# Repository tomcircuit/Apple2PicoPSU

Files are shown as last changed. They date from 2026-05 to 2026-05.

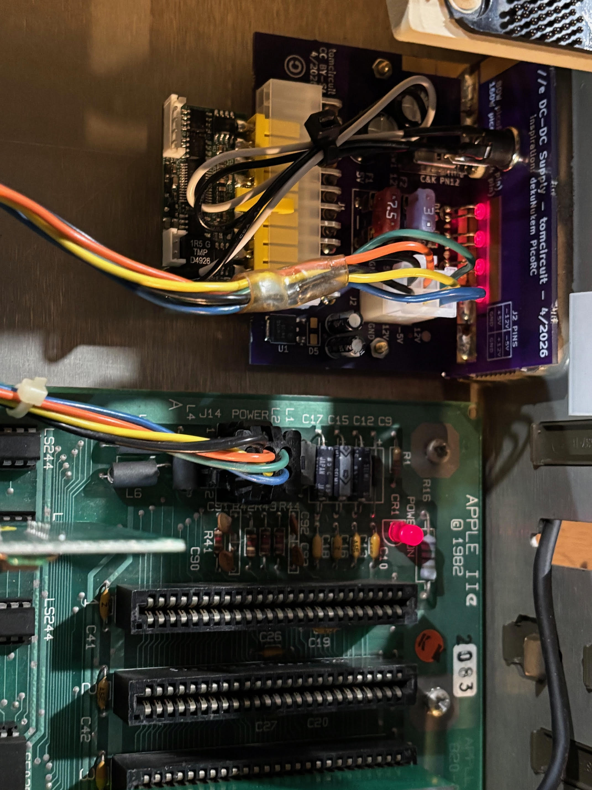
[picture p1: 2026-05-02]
Media/installed_interior.jpg

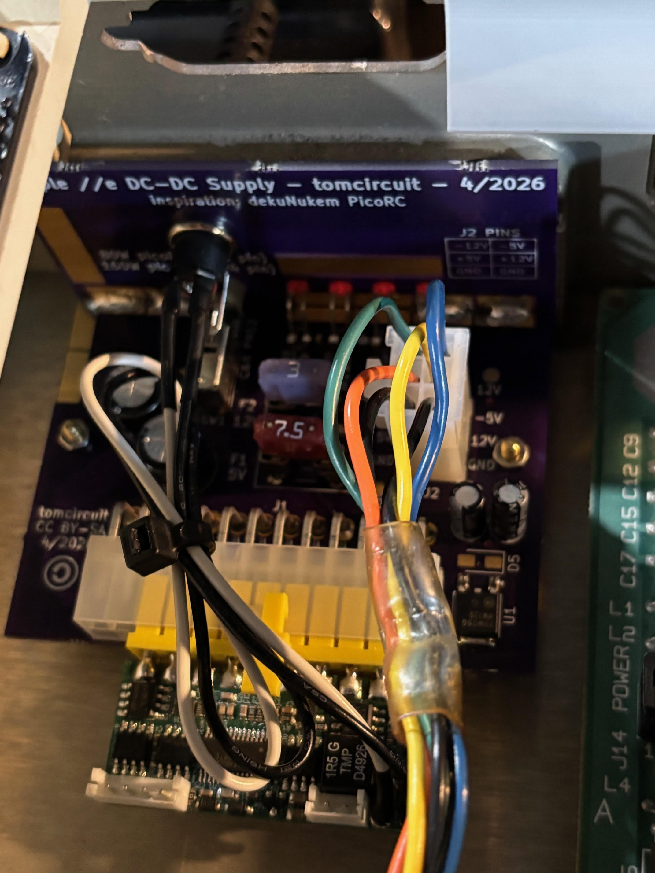
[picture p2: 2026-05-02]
Media/installed_interior_2.jpg

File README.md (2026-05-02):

# Apple 2 Pico PSU
12V Input Power Supply retrofit for vintage Apple //e  computers

Many vintage Apple(R) ][ and // series computers suffer from power supply failure. These computers were fitted with switching power supplies (SMPS) that, for the time, were notable for their lightweight, quiet, and efficient characteristics. Time, however, has not been kind to these supplies, which are vulnerable to aging. There is no drop-in replacment unit, so most enthusiasts are forced to either repair their supply or replace with a modern retrofit. This project is of the latter type, and my motivation was when my Apple //e computer's power supply emitted the dreaded "magic smoke" (AFTER a complete re-cap, mind you) and resisted my efforts at repair.

First and foremost, this project is insprired by the "PicoRC" project family by DekuNukem, currently found here: https://github.com/dekuNukem/PicoRC
Note that that project is licensed under MIT License terms:

```
MIT License

Copyright (c) 2022 dekuNukem

Permission is hereby granted, free of charge, to any person obtaining a copy
of this software and associated documentation files (the "Software"), to deal
in the Software without restriction, including without limitation the rights
to use, copy, modify, merge, publish, distribute, sublicense, and/or sell
copies of the Software, and to permit persons to whom the Software is
furnished to do so, subject to the following conditions:

The above copyright notice and this permission notice shall be included in all
copies or substantial portions of the Software.

THE SOFTWARE IS PROVIDED "AS IS", WITHOUT WARRANTY OF ANY KIND, EXPRESS OR
IMPLIED, INCLUDING BUT NOT LIMITED TO THE WARRANTIES OF MERCHANTABILITY,
FITNESS FOR A PARTICULAR PURPOSE AND NONINFRINGEMENT. IN NO EVENT SHALL THE
AUTHORS OR COPYRIGHT HOLDERS BE LIABLE FOR ANY CLAIM, DAMAGES OR OTHER
LIABILITY, WHETHER IN AN ACTION OF CONTRACT, TORT OR OTHERWISE, ARISING FROM,
OUT OF OR IN CONNECTION WITH THE SOFTWARE OR THE USE OR OTHER DEALINGS IN THE
SOFTWARE.
```

I did not directly modify the Eagle PCB nor Schematic files, and this work is my own, but I do feel that it is only proper to give DekuNukem attribution for the inspiration for this project. I license my project under CC-BY-SA-4.0 which can accept an MIT License as an "inbound license", in the event that my work is determined to be derivative after all.

There, that out of the way...

It's a **Great Idea** to move the AC-DC converter to the **outside of the Apple's case** for many reasons some of which are: it's heavy, it generates heat, and it allows for the possiblity to scale the PSU Wattage as required by the peripheral load. Any 12VDC supply with sufficient wattage and mating connector can be used, so that only 12VDC goes into the computer via the rear panel.

The **PicoPSU** units that are aimed at Small Form Factor (SFF) PC's are an ideal solution to convert the incoming 12VDC to +5V, +15V and -12V. These are available from many sources, in varying Wattages. I chose an 80W type for my own use, which should be more than sufficient. All that is missing is the -5V which is (questionably) required by the Apple motherboard.

Like the PicoRC for the Apple, my Apple2PicoPSU provides a power switch, a 24-pin Molex connector for the PicoPSU, fuses for the +5V and +12V voltage rails, and a -5V regulator for the 'missing' rail. I adoped a similar "PCB-welded" construction of a back panel and circuit board, because it seemed like a very convenient way to satisfy the mechanical aspects.

Improvements over the original PicoRC for the Apple are the following:
* power switch suitable for switching the low-current PicoPSU enable
* the 7905 voltage regulator would benefit from some sort of heatsinking
* LED for each voltage rail, visible from the outside of the case
* copper tracks sized sufficiently for the anticipated current demand

It is this last point in particular that really drove me to re-engineer this concept; I am quite skeptical of the copper track widths used in the original. I have sized the copper tracks for at least 8A on the 5V rail, and 4A on the 12V rail, assuming 1oz Cu and a modest 15C temperature rise over ambient.

My project was executed in the very capable open-source and "completely free" KiCad 10.0 which is well supported by the usual Operating Systems suspects...

Complete project writeup, including assembly instructions, can be found on Hackaday
https://hackaday.io/project/205643-a-modern-psu-for-my-apple-e

tomcircuit
01-MAY-2026

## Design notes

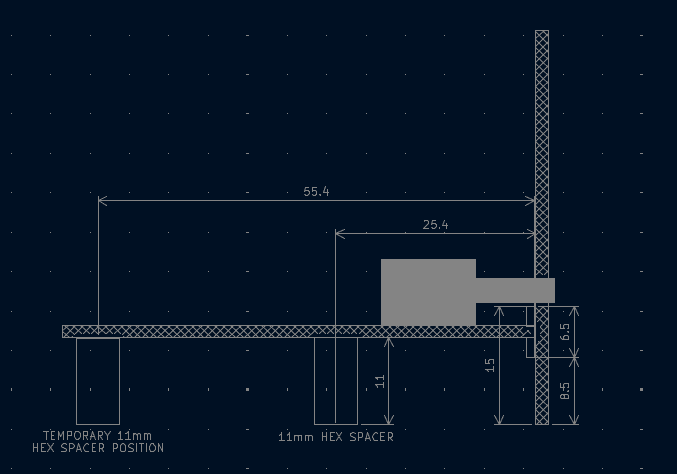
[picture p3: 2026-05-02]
Media/mechanical_assy_side.png

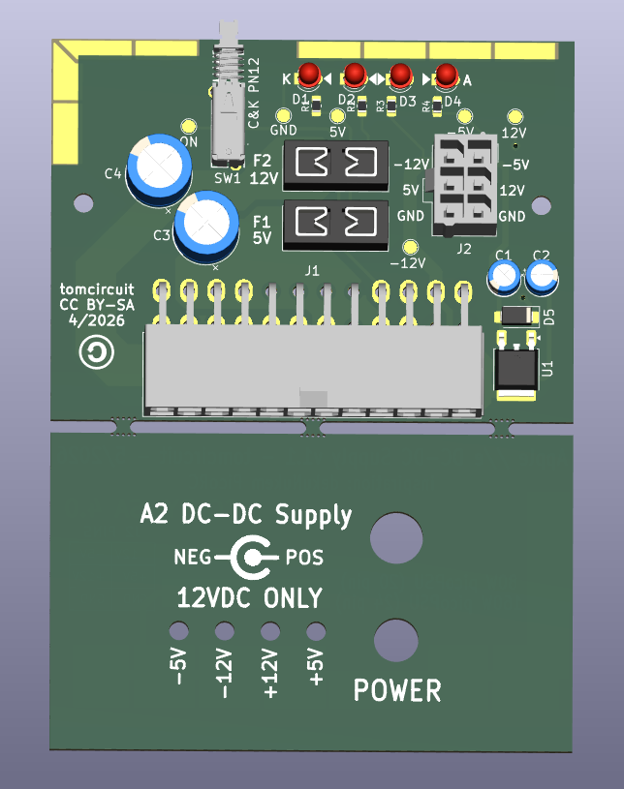
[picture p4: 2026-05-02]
Media/kicad_3d_model.png

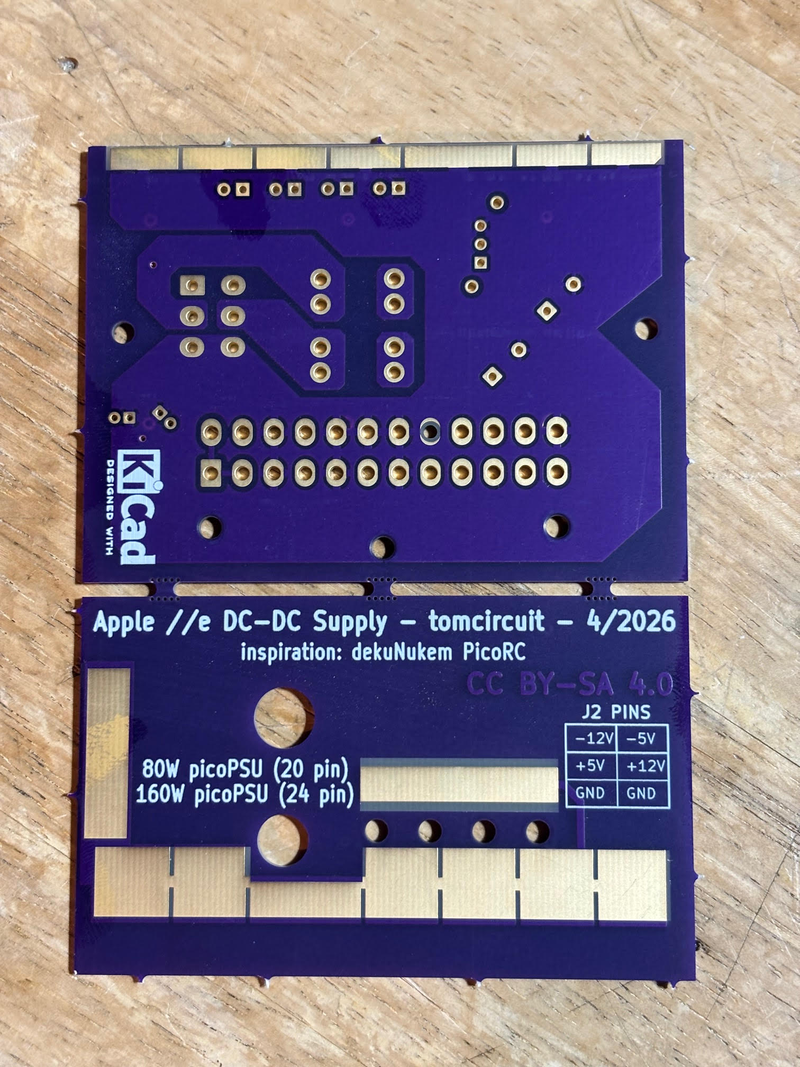
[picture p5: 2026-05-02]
Media/pcb_bare_bottom.jpg

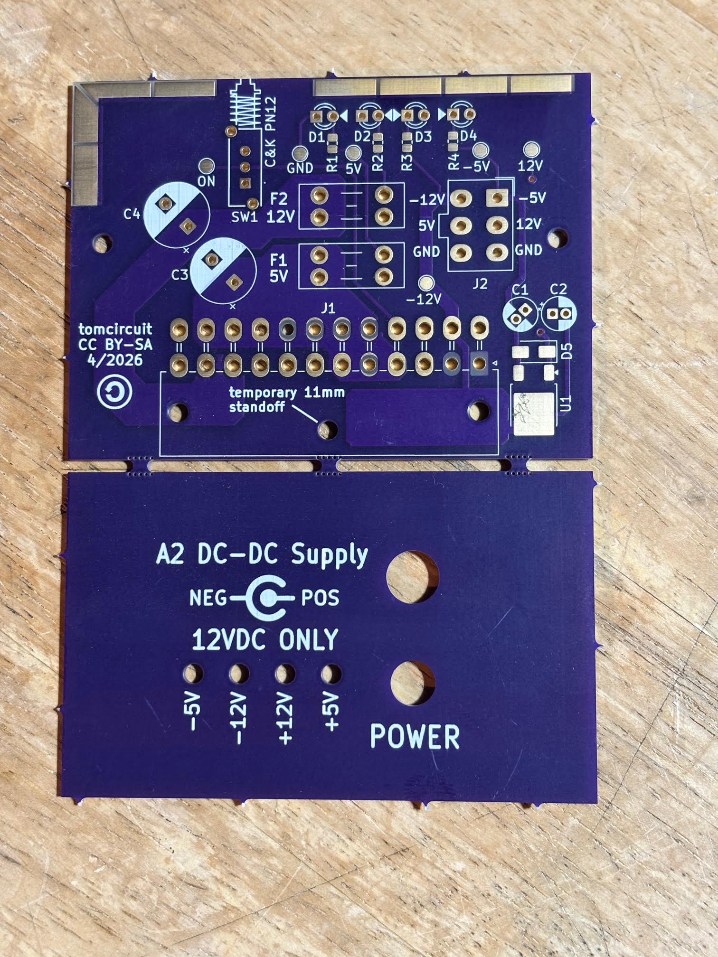
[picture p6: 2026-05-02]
Media/pcb_bare_top.jpg

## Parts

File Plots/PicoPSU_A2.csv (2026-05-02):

Id | Designator | Footprint | Quantity | Designation | Supplier and ref
1 | C1 | CP_Radial_D5.0mm_P2.00mm | 1 | 1uF
2 | C2 | CP_Radial_D5.0mm_P2.00mm | 1 | 2.2uF
3 | C3, C4 | CP_Radial_D10.0mm_P5.00mm | 2 | 470uF
4 | D1 | LED_D3.0mm | 1 | 5V
5 | D2 | LED_D3.0mm | 1 | 12V
6 | D3 | LED_D3.0mm | 1 | -12V
7 | D4 | LED_D3.0mm | 1 | -5V
8 | D5 | D_SMA | 1 | US1A
9 | F1 | Fuseholder_Blade_Mini_Keystone_3568 | 1 | 5V
10 | F2 | Fuseholder_Blade_Mini_Keystone_3568 | 1 | 12V
11 | J1 | Molex_Mini-Fit_Jr_5569-24A2_2x12_P4.20mm_Horizontal | 1 | PICO PSU
12 | J2 | Molex_Mini-Fit_Jr_5566-06A_2x03_P4.20mm_Vertical | 1 | APPLE MB
13 | R1, R4 | R_0805_2012Metric_Pad1.20x1.40mm_HandSolder | 2 | 330
14 | R2, R3 | R_0805_2012Metric_Pad1.20x1.40mm_HandSolder | 2 | 1K
15 | SW1 | PN12SHSA03QE | 1 | POWER
16 | TP5 | TestPoint_Pad_D2.0mm | 1 | ON
17 | U1 | TO-252-2 | 1 | MC79M05

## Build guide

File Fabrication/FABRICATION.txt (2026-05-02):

Here are Gerber and NC Drill files that are necessary for PCB fabrication

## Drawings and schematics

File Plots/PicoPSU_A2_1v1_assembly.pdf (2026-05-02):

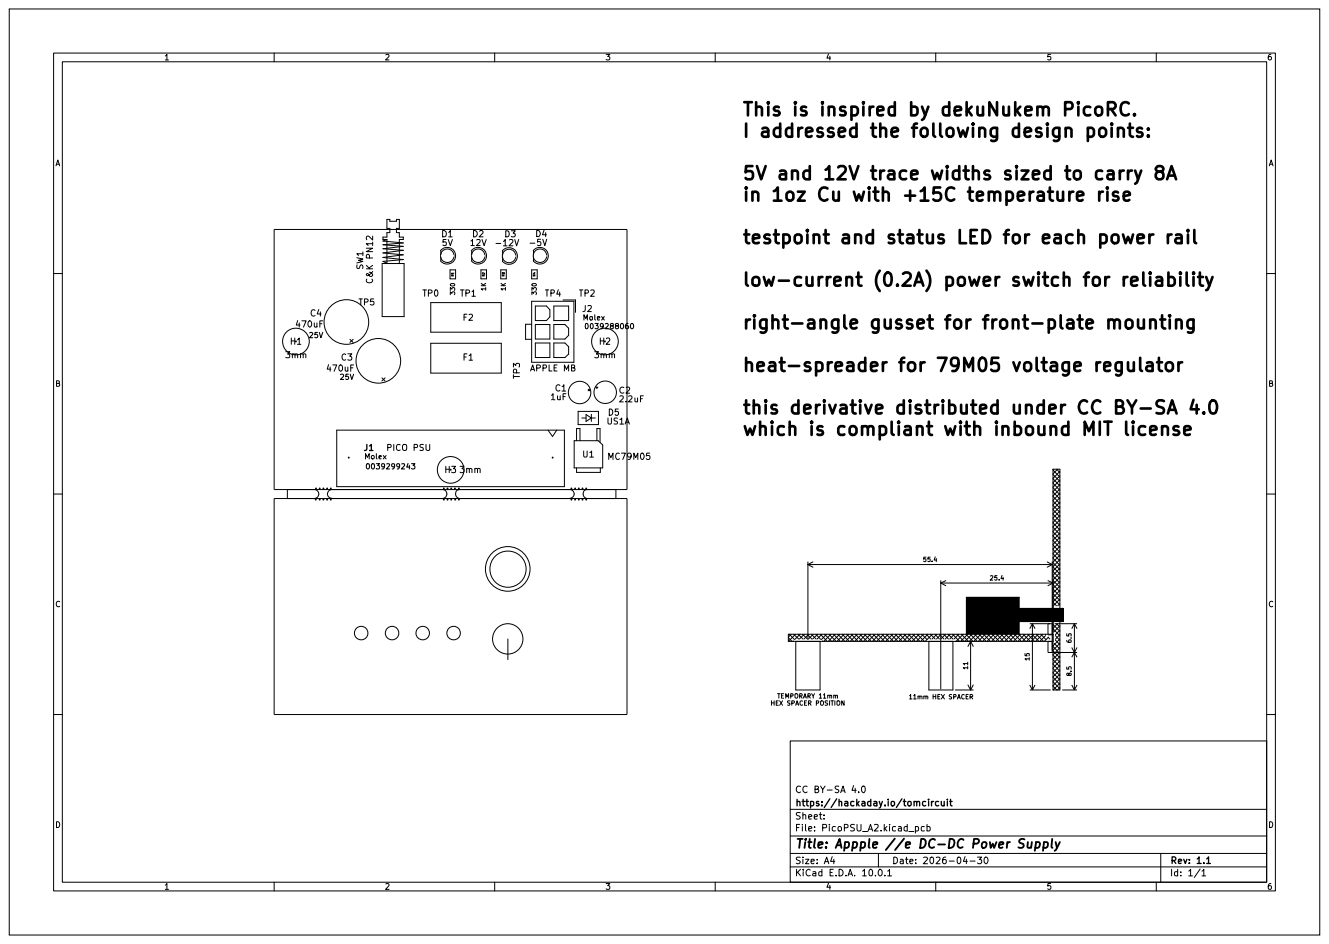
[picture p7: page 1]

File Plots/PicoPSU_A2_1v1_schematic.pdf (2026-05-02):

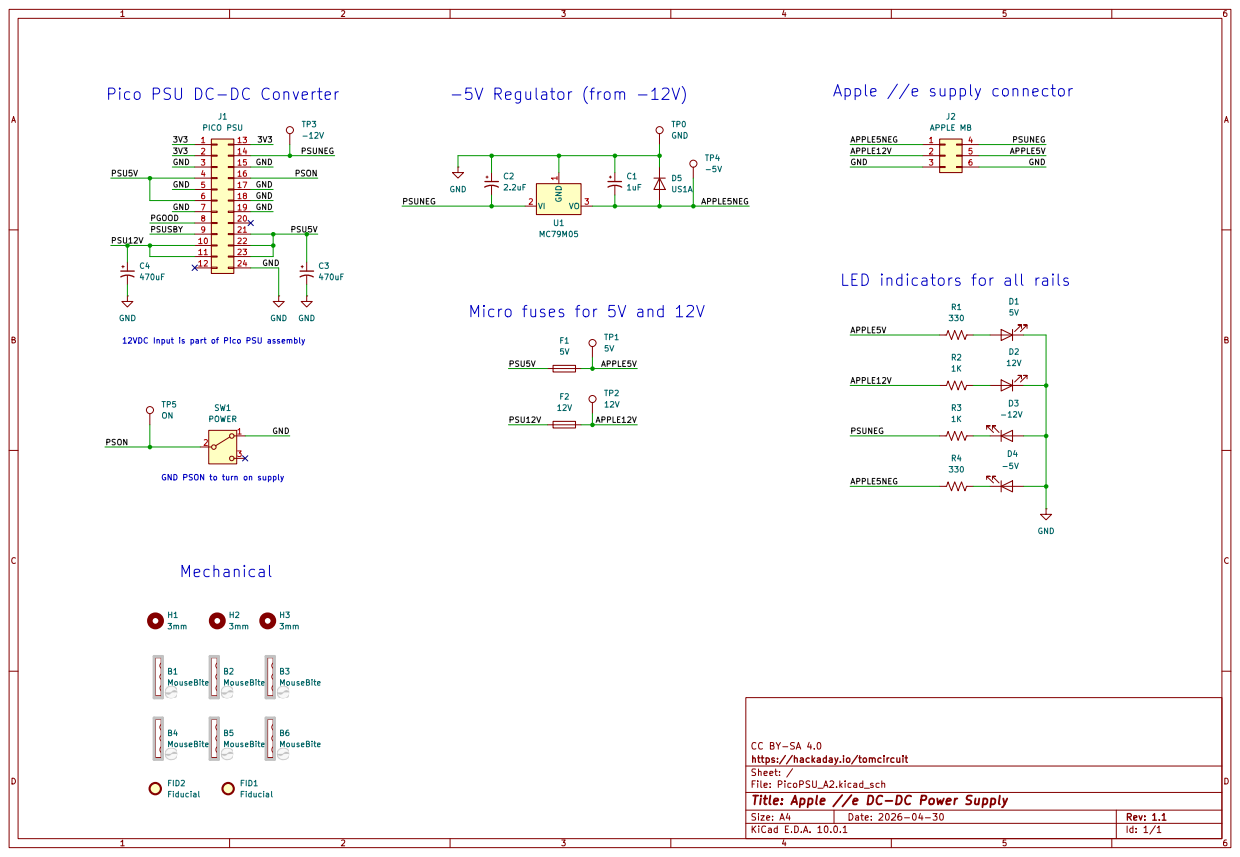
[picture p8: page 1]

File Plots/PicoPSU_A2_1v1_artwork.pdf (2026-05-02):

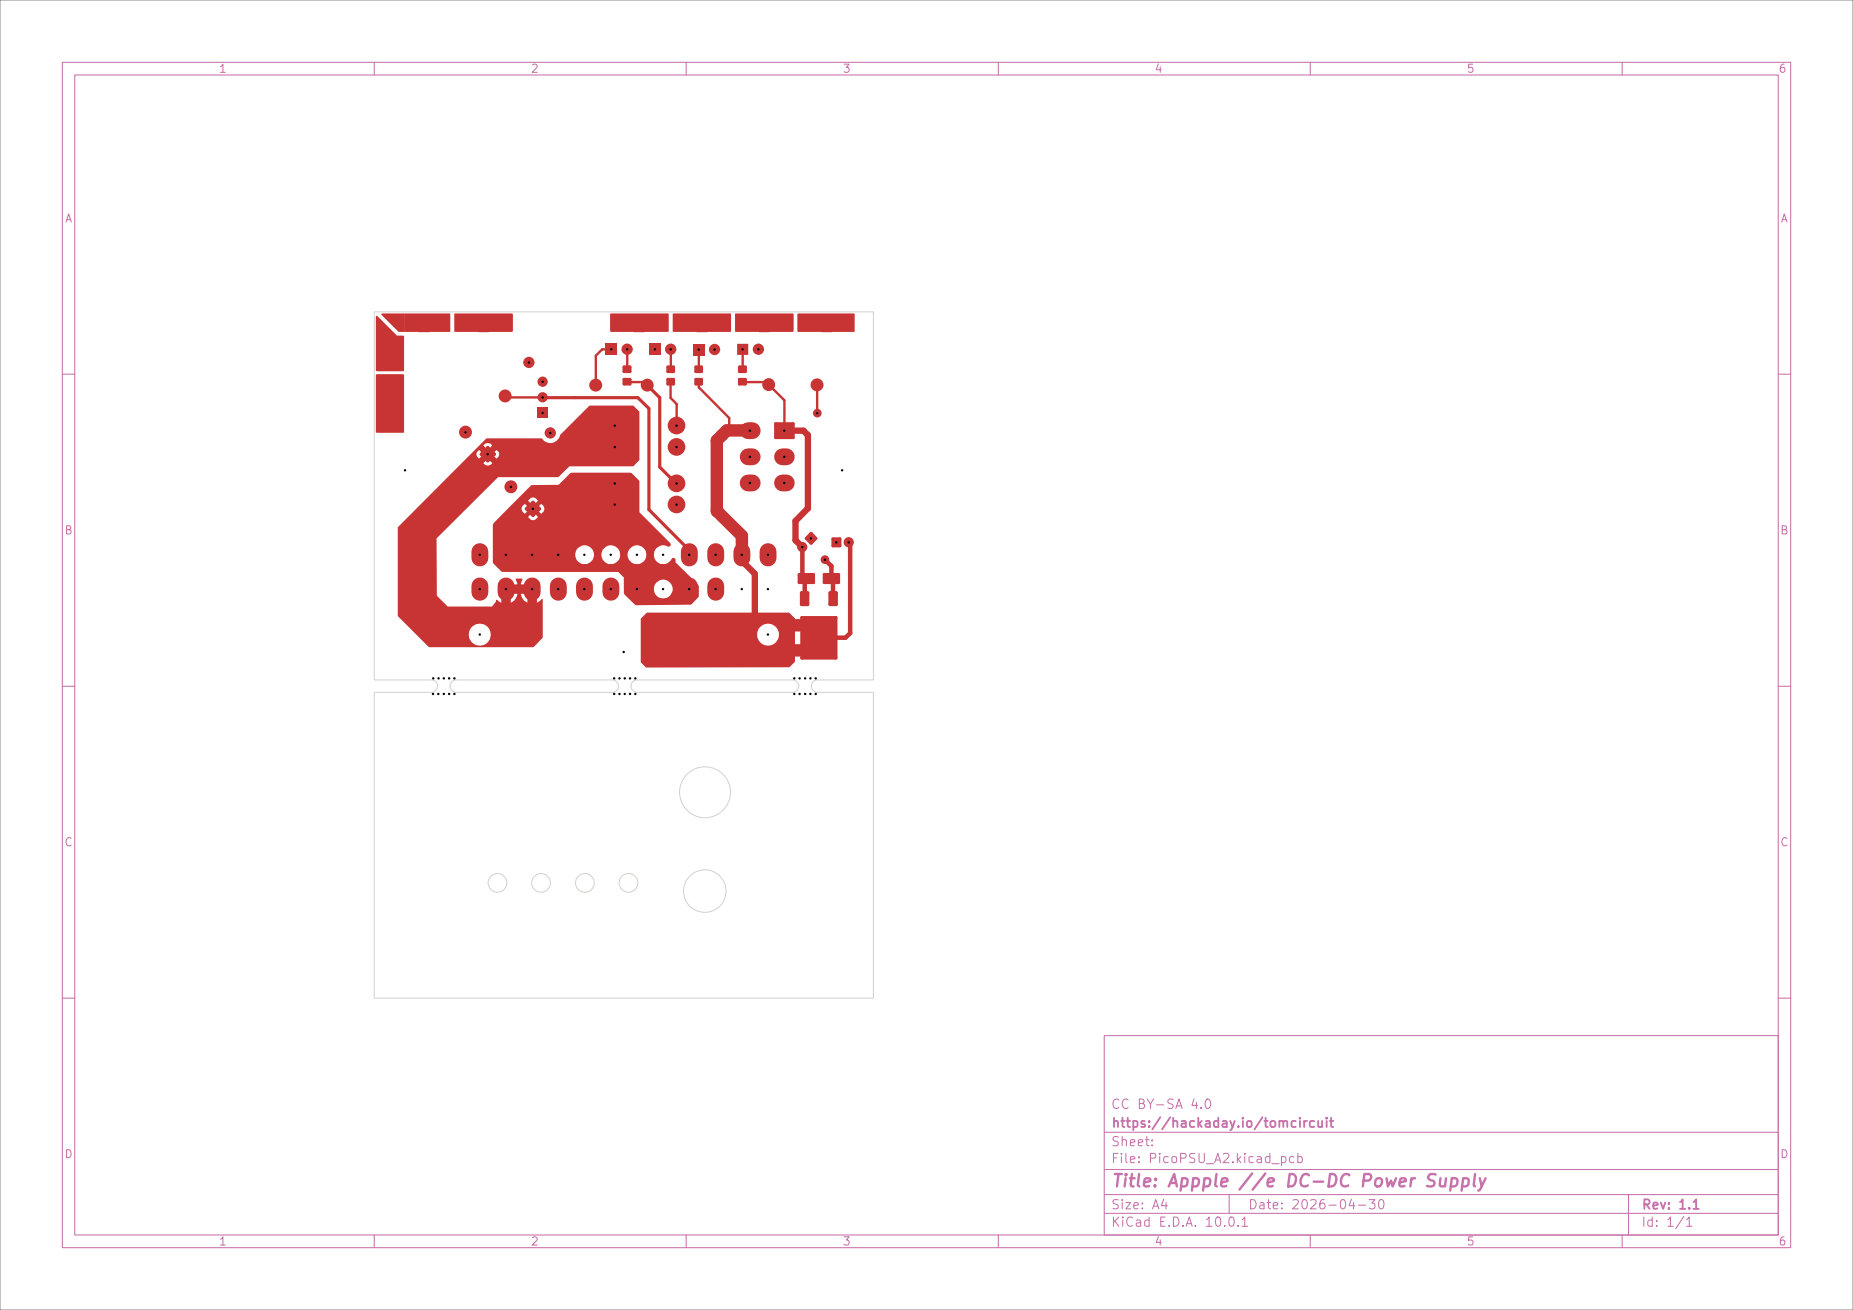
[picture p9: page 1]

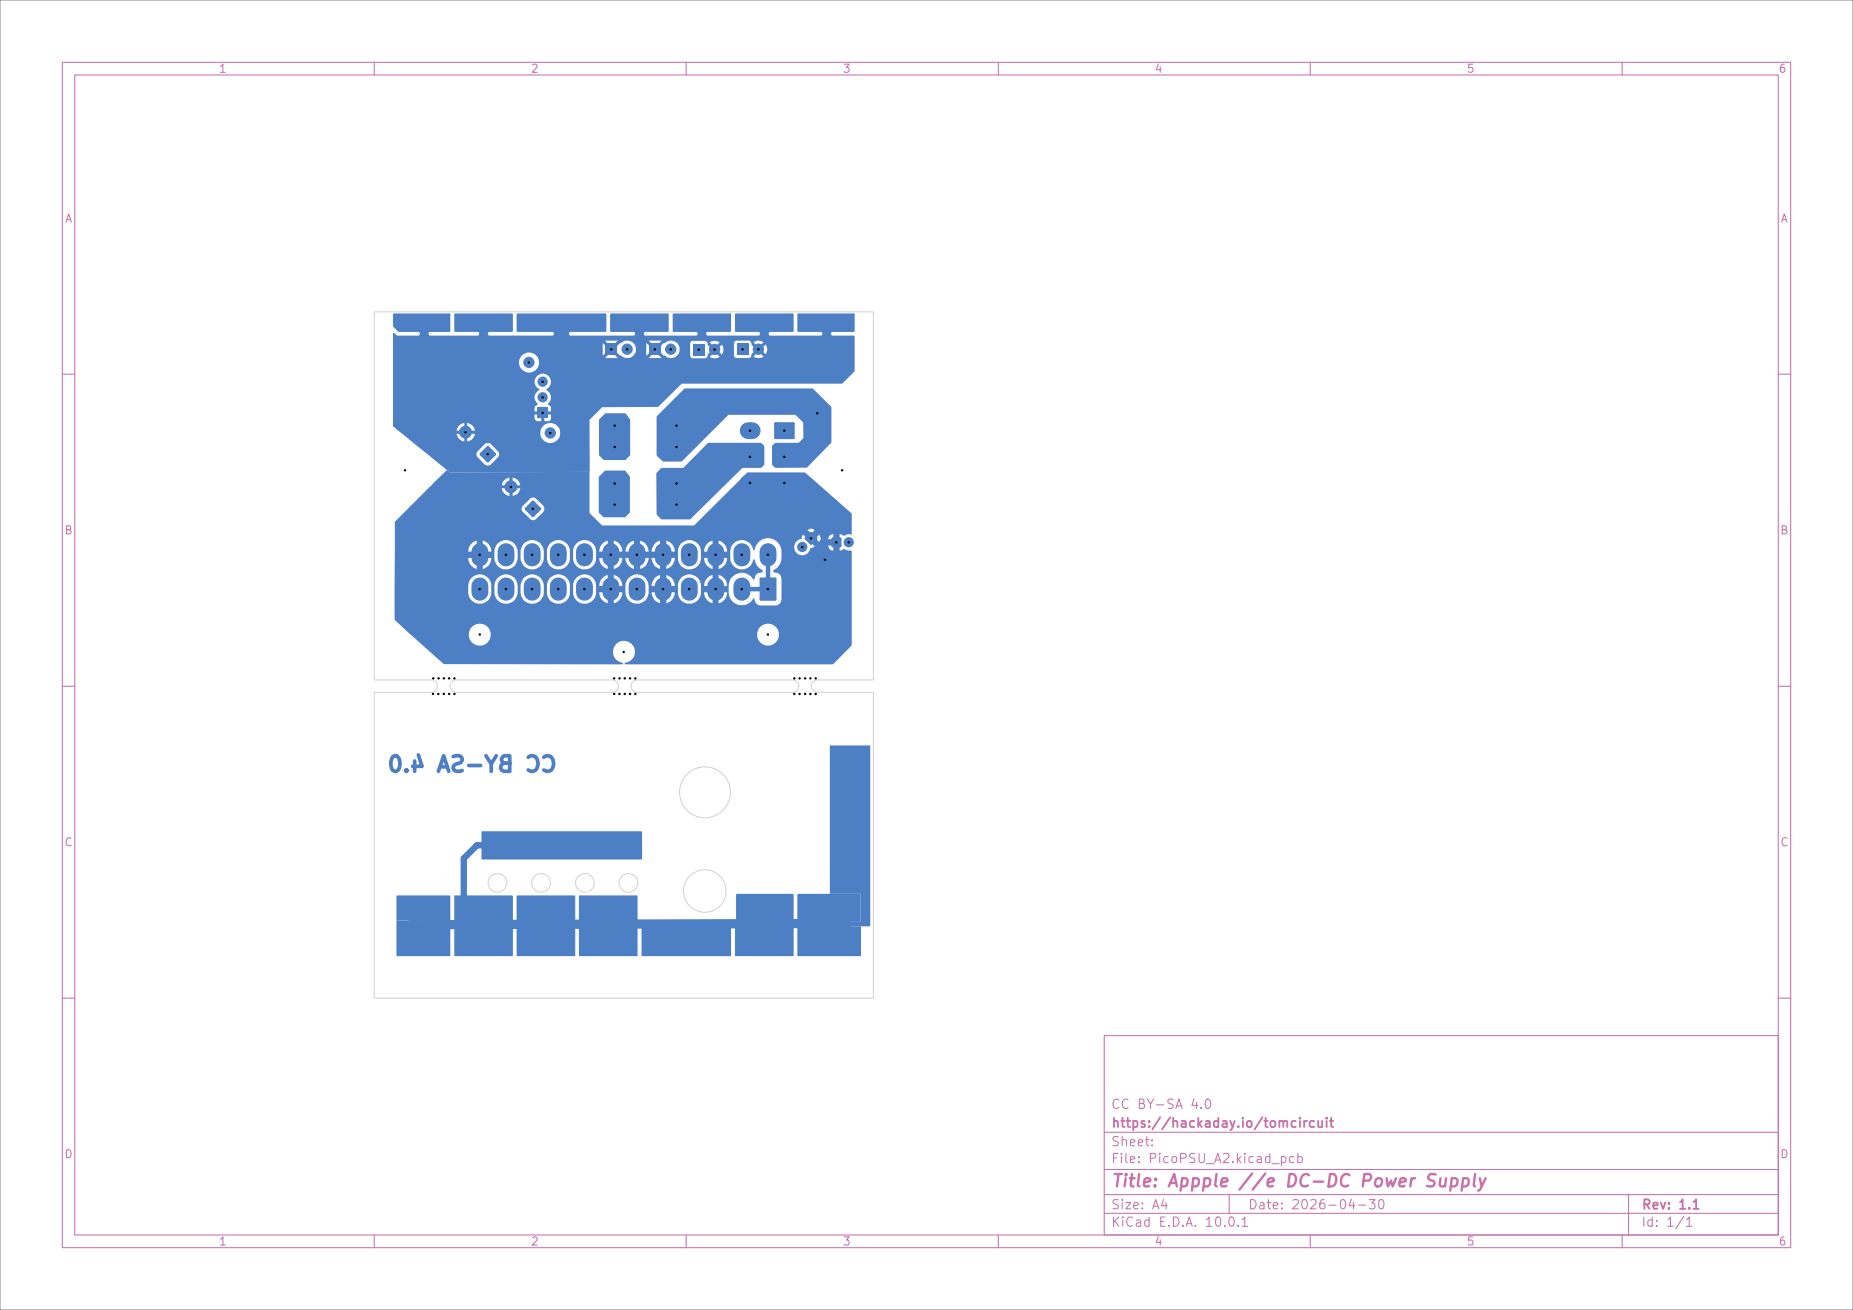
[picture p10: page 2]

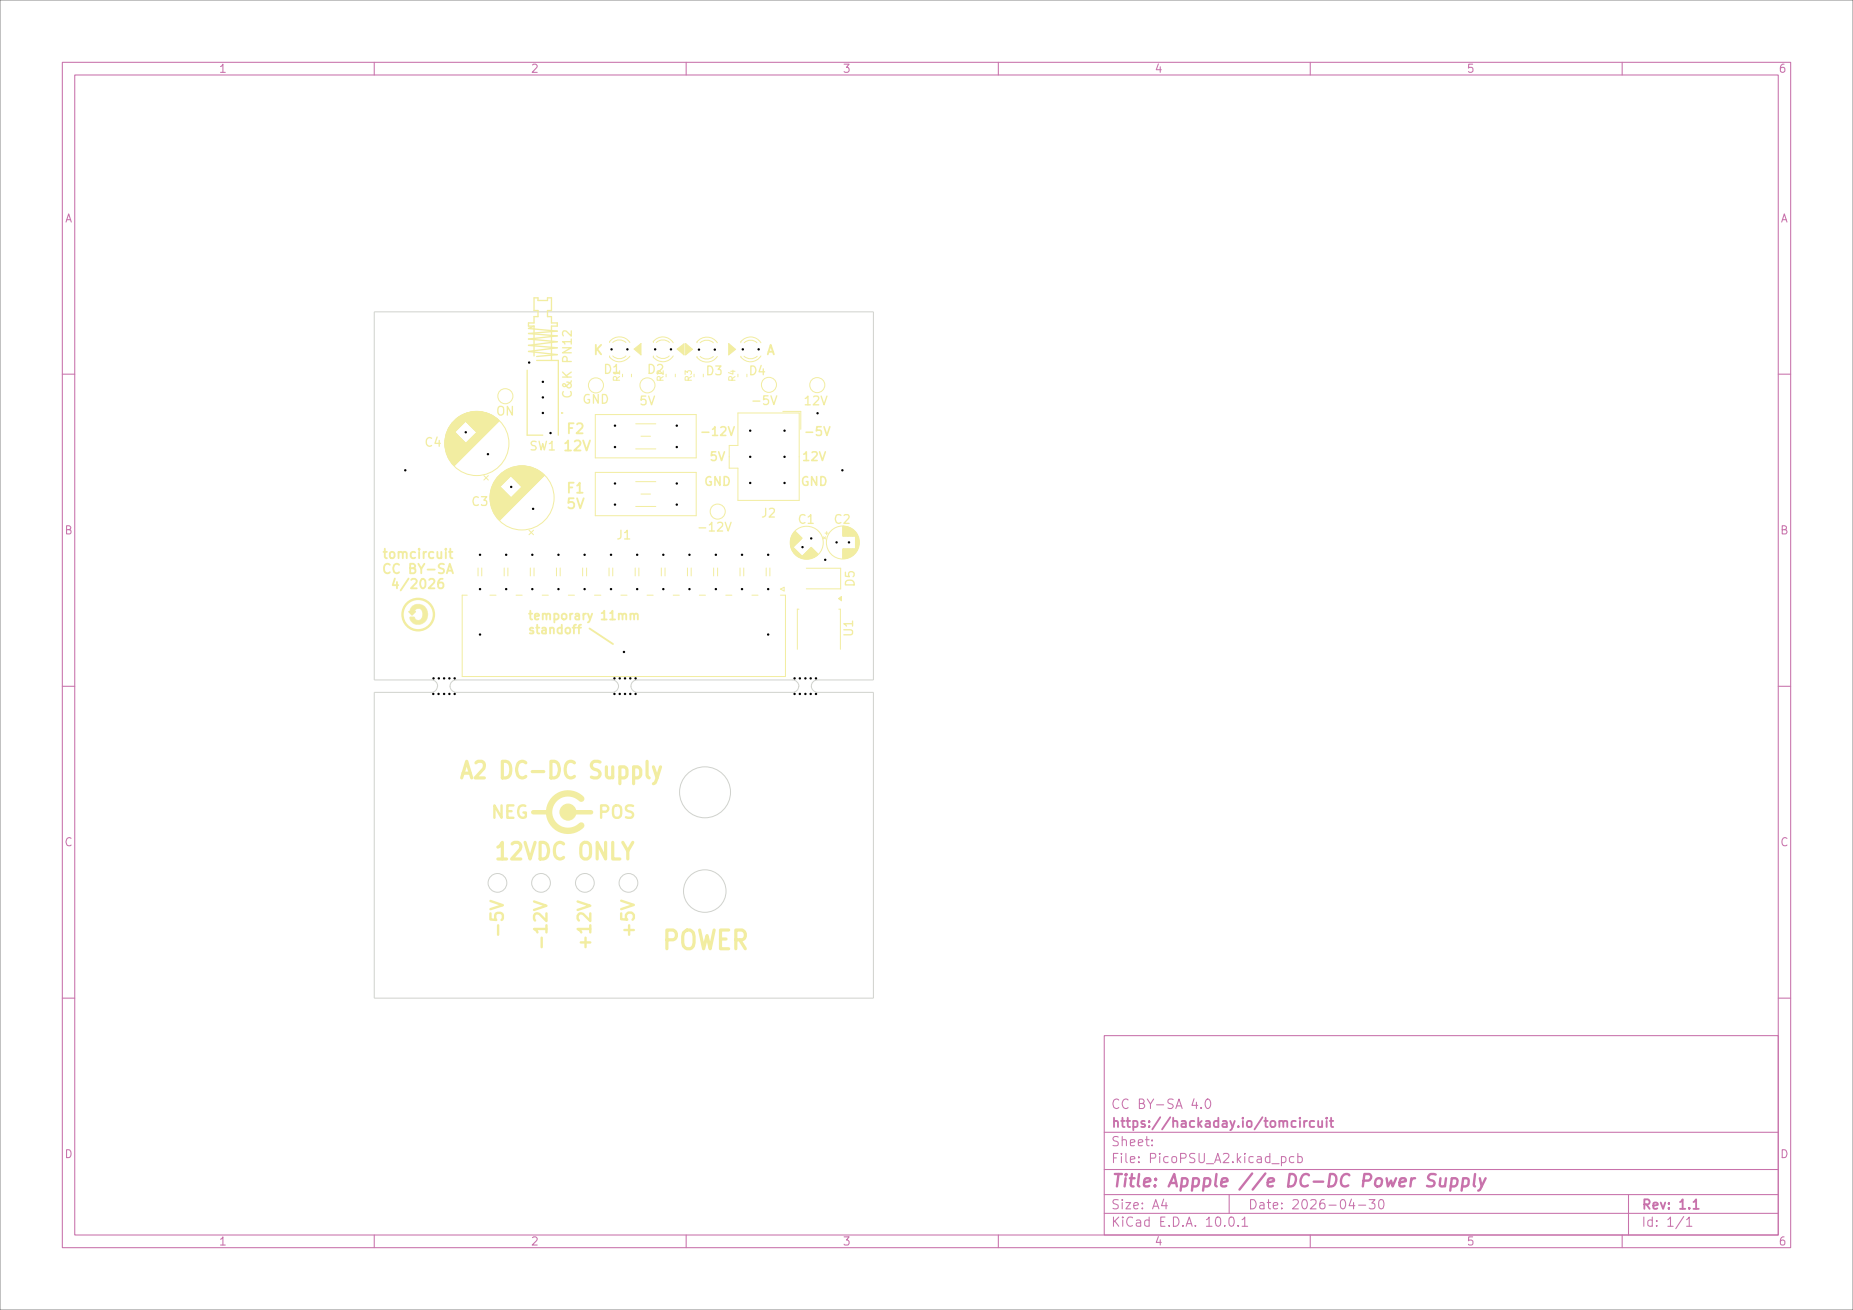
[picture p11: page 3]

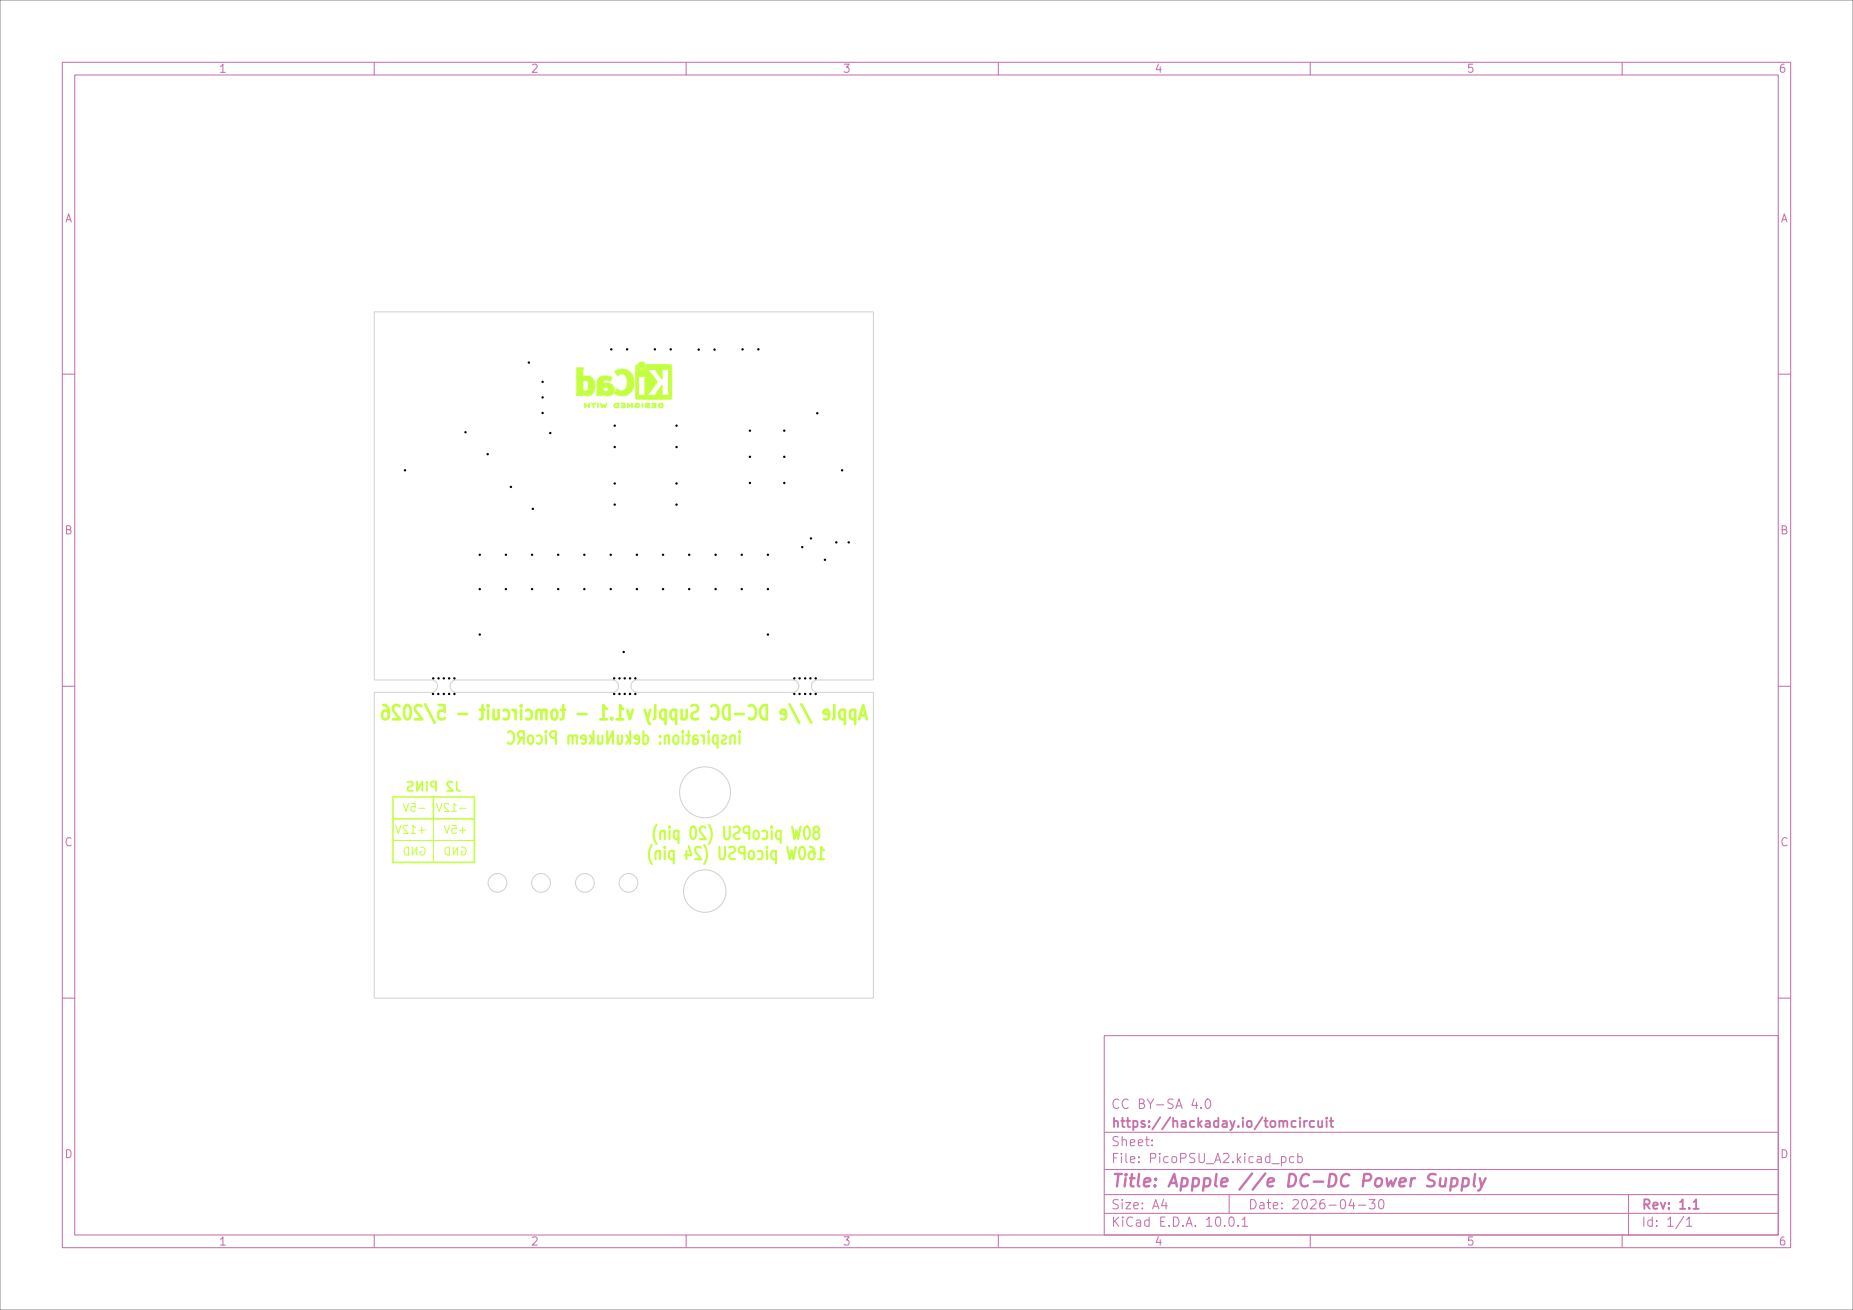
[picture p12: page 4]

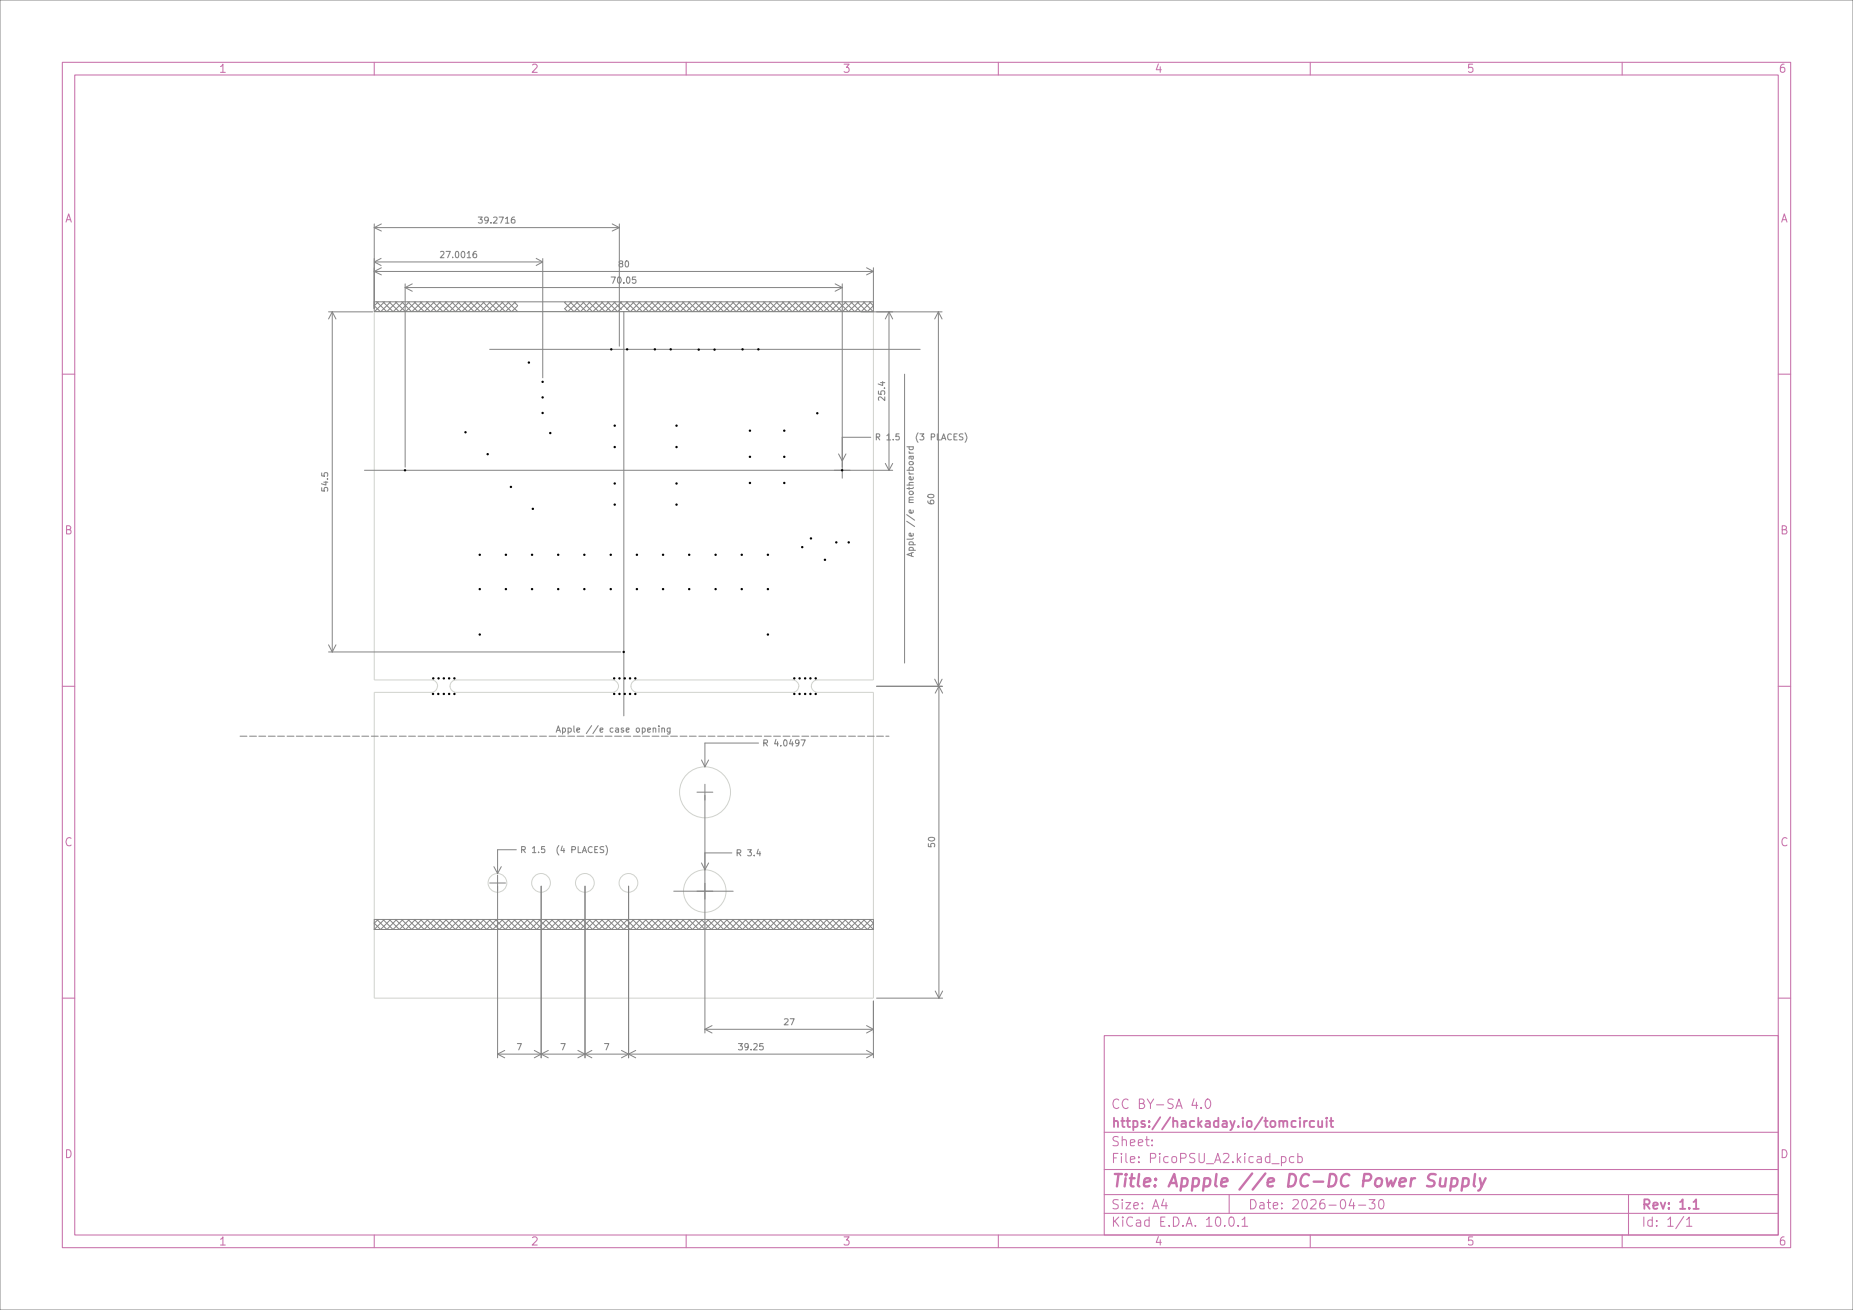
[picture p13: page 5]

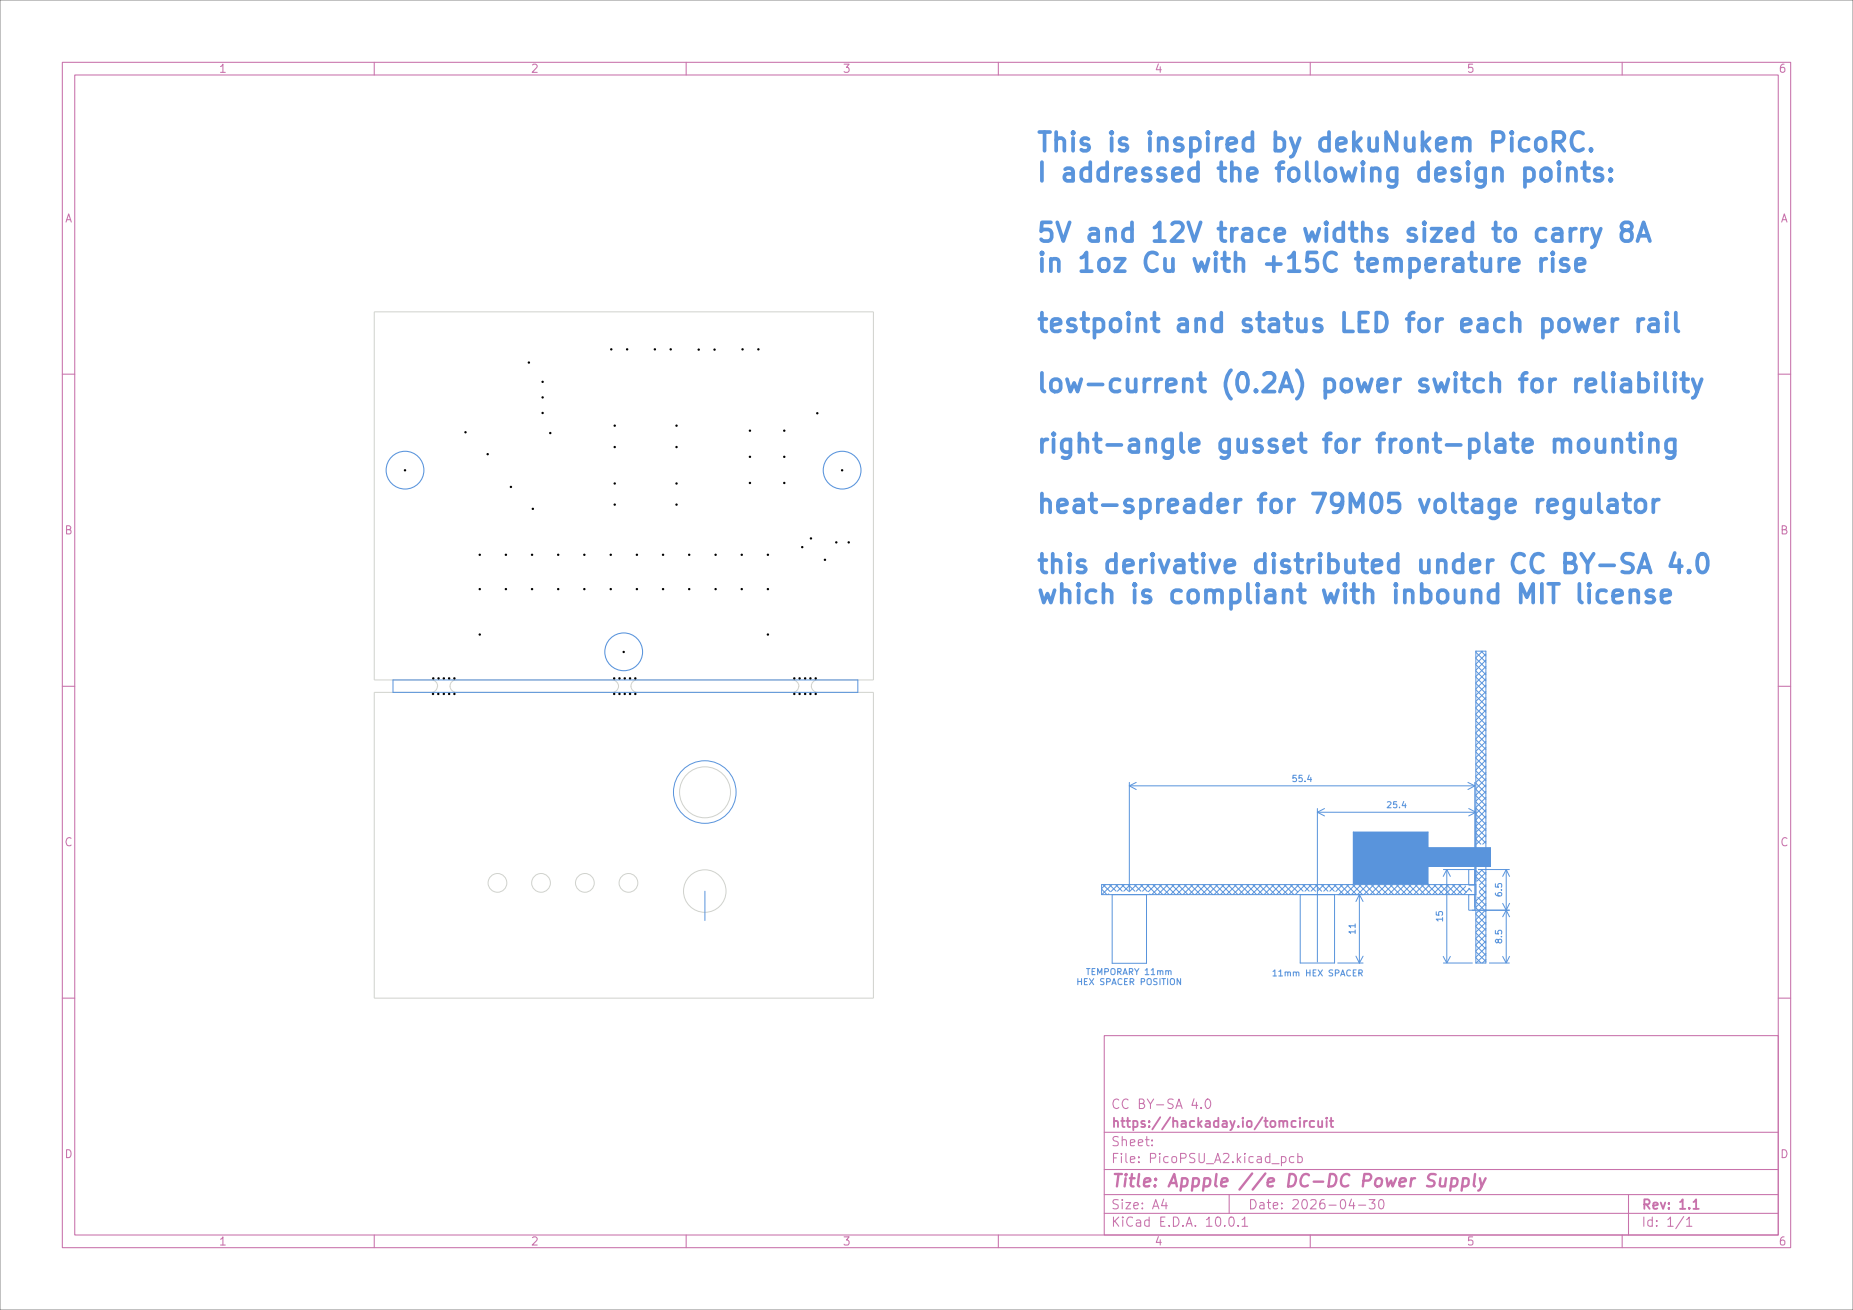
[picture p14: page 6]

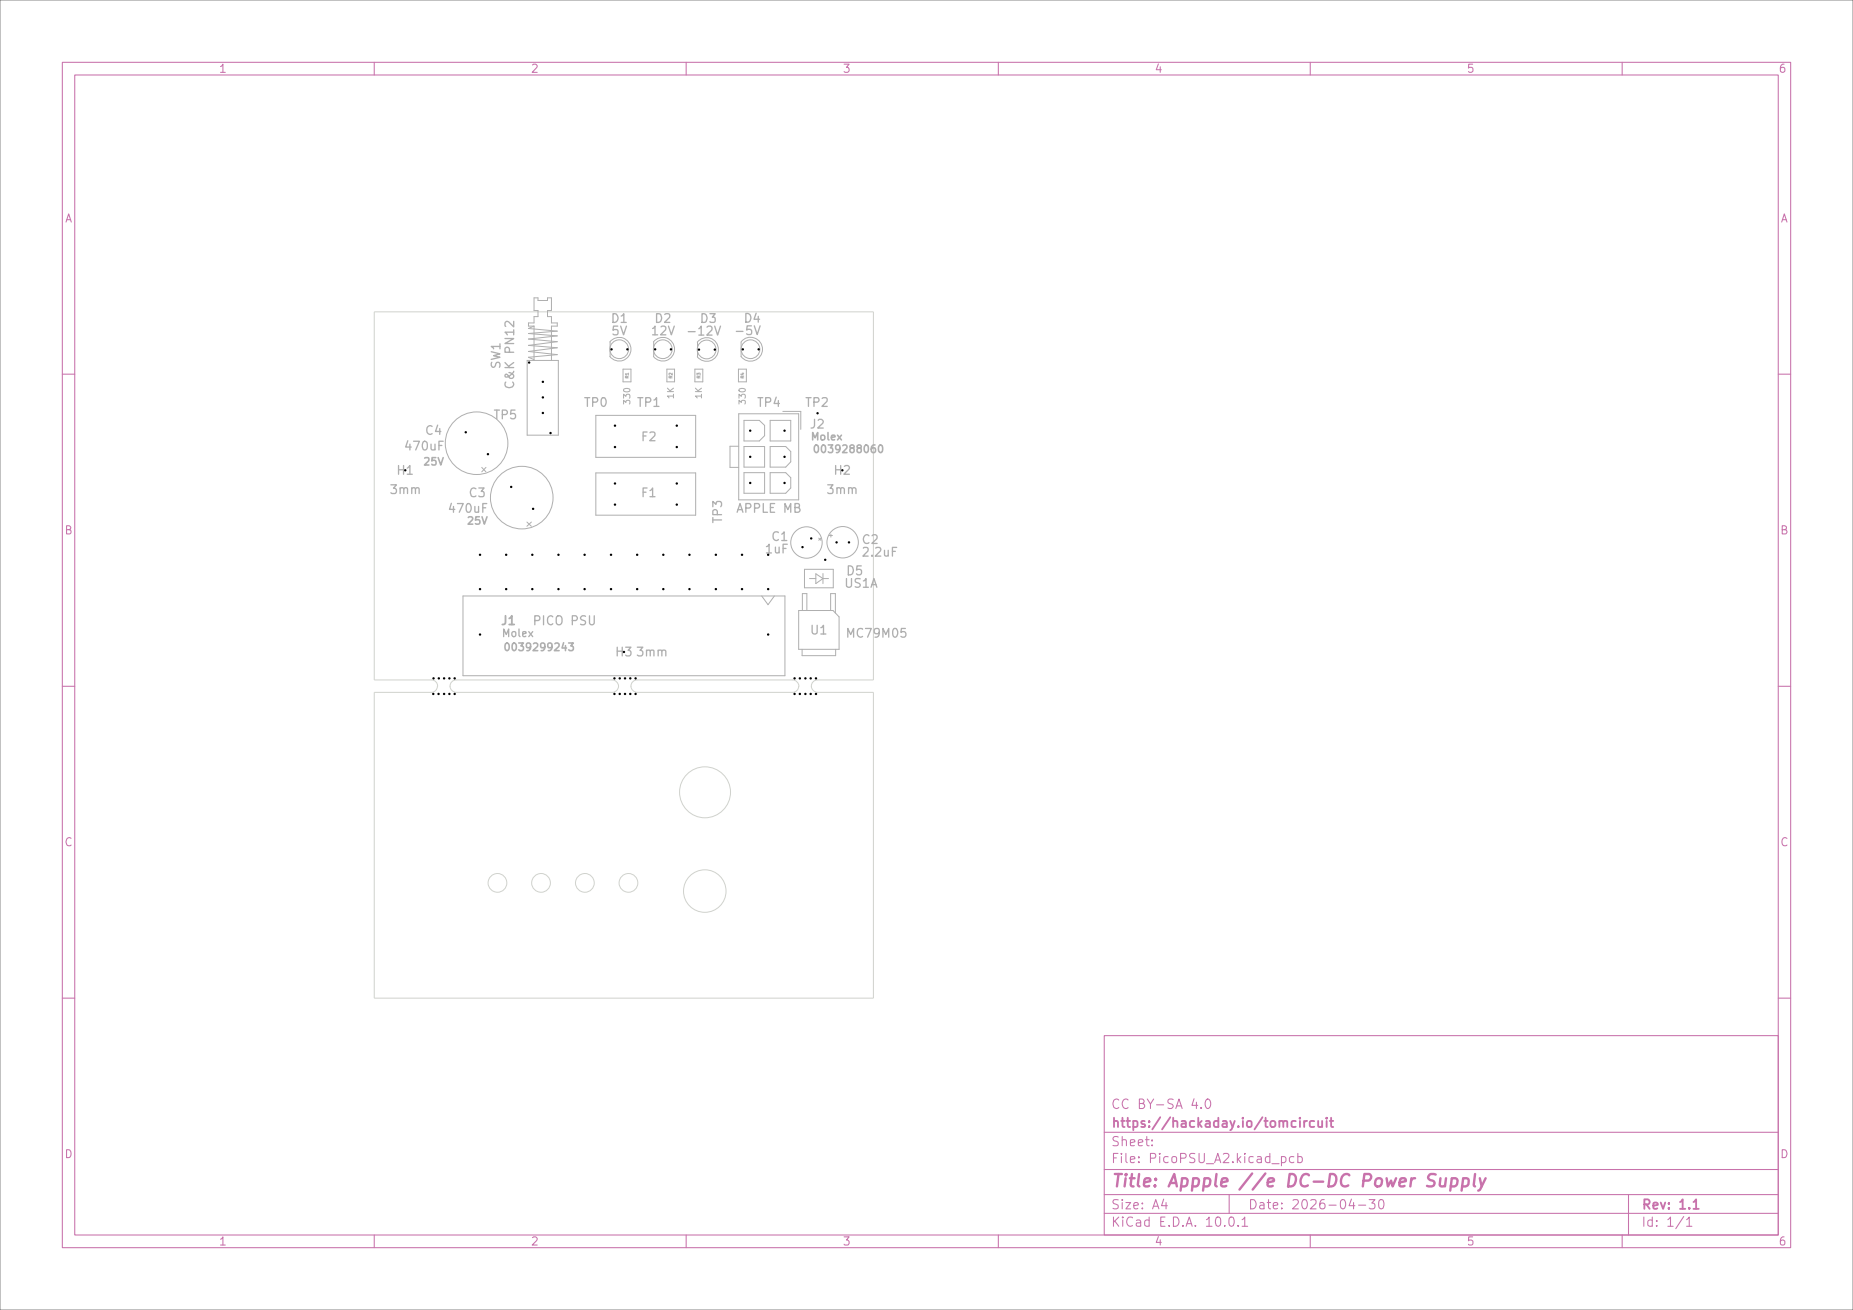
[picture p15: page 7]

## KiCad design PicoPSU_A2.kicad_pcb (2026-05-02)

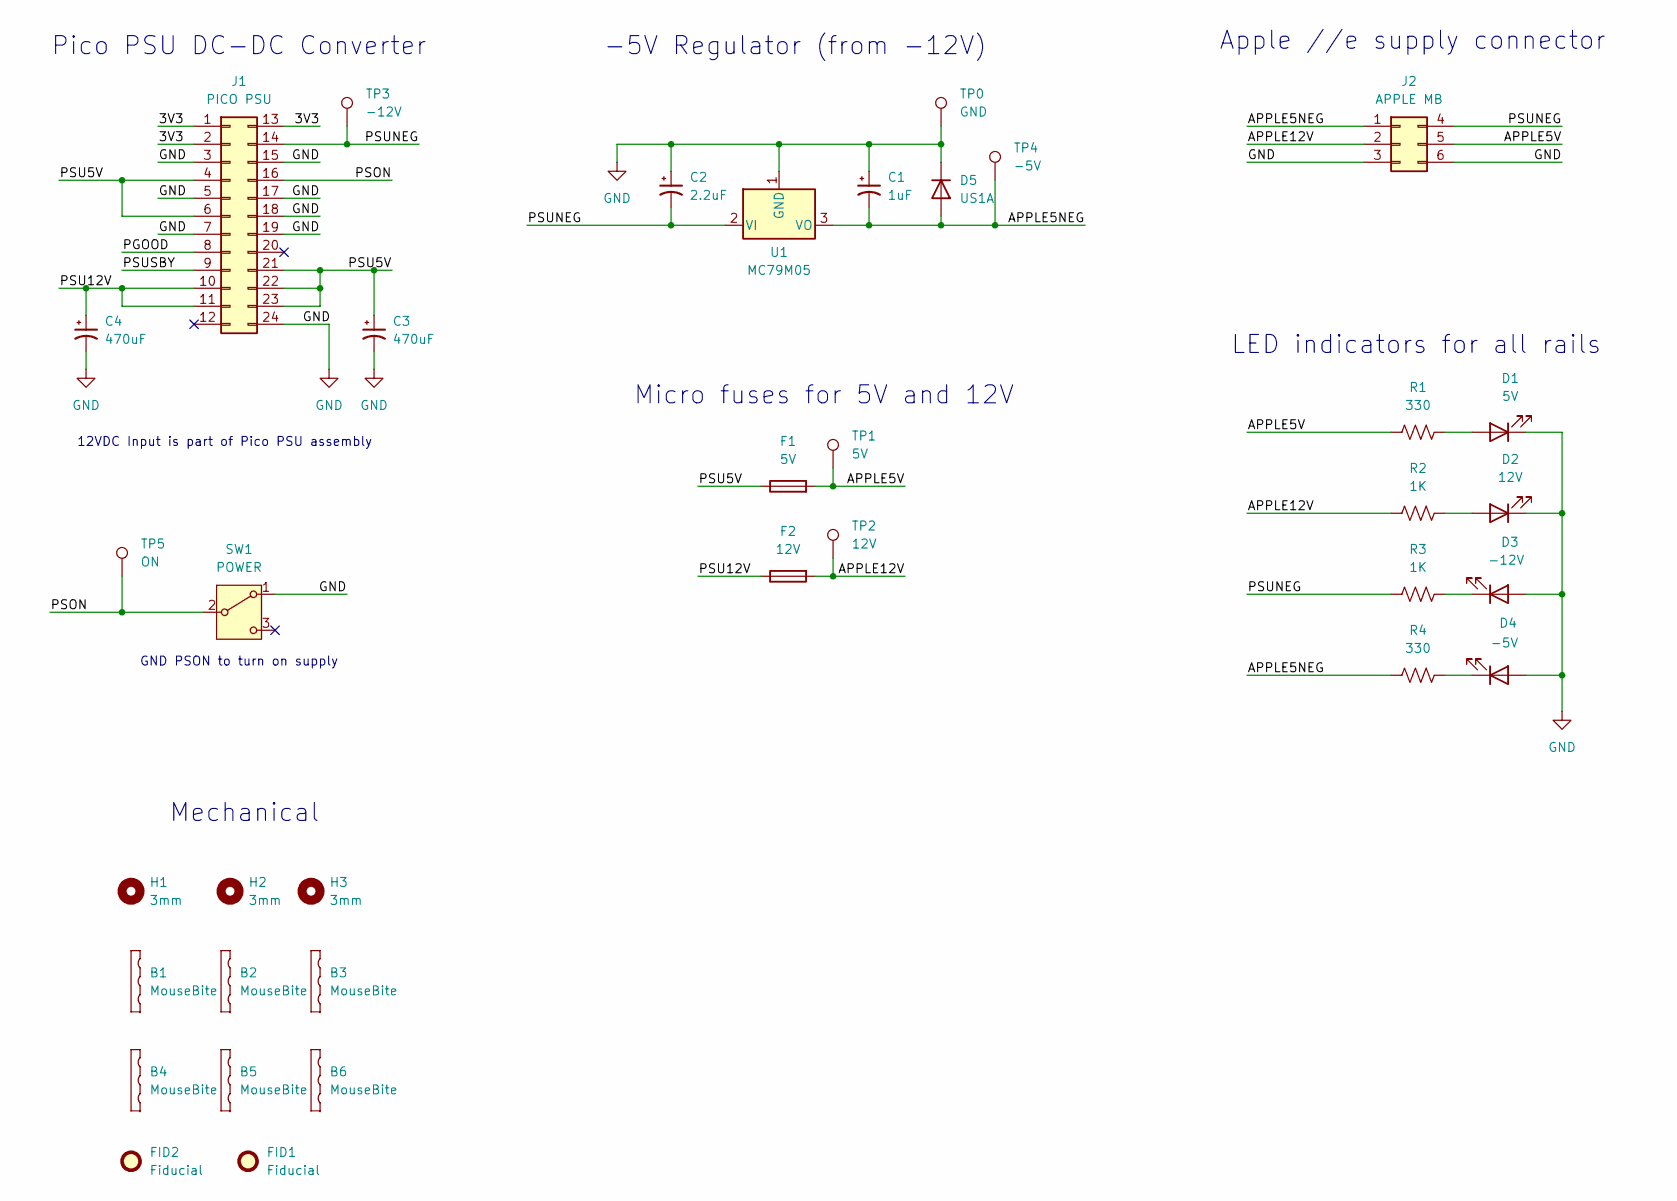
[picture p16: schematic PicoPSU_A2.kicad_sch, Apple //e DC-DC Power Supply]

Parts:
B1, B2, B3, B4, B5, B6: MouseBite; MouseBite-Part_2.0x2.0mm_inset_D0.5mm_P0.85mm_5h
C1: 1uF; CP_Radial_D5.0mm_P2.00mm
C2: 2.2uF; CP_Radial_D5.0mm_P2.00mm
C3, C4: 470uF; CP_Radial_D10.0mm_P5.00mm
D1: 5V; LED_D3.0mm
D2: 12V; LED_D3.0mm
D3: -12V; LED_D3.0mm
D4: -5V; LED_D3.0mm
D5: US1A; D_SMA
F1: 5V; Fuseholder_Blade_Mini_Keystone_3568
F2: 12V; Fuseholder_Blade_Mini_Keystone_3568
FID1: Fiducial; KiCad-Logo2_6mm_SilkScreen
FID2: Fiducial; Symbol_CC-ShareAlike_CopperTop_Small
H1, H2, H3: 3mm; MountingHole_3mm
J1: PICO PSU; Molex_Mini-Fit_Jr_5569-24A2_2x12_P4.20mm_Horizontal; MPN 0039299243
J2: APPLE MB; Molex_Mini-Fit_Jr_5566-06A_2x03_P4.20mm_Vertical; MPN 0039288060
R1, R4: 330; R_0805_2012Metric
R2, R3: 1K; R_0805_2012Metric
SW1: POWER; PN12SHSA03QE; MPN PN12SHSA03QE
TP0: GND; TestPoint_Pad_D2.0mm
TP1: 5V; TestPoint_Pad_D2.0mm
TP2: 12V; TestPoint_Pad_D2.0mm
TP3: -12V; TestPoint_Pad_D2.0mm
TP4: -5V; TestPoint_Pad_D2.0mm
TP5: ON; TestPoint_Pad_D2.0mm
U1: MC79M05; TO-252-2; MPN MC79M05CDTRKG

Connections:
/3V3: J1.1, J1.2, J1.13
/APPLE5NEG: C1.2, D5.2 (A), J2.1, R4.1, TP4.1 (1_1), U1.3 (VO)
/APPLE5V: F1.2, J2.5, R1.1, TP1.1 (1_1)
/APPLE12V: F2.2, J2.2, R2.1, TP2.1 (1_1)
/PGOOD: J1.8
/PSON: J1.16, SW1.2 (B), TP5.1 (1_1)
/PSU5V: C3.1, F1.1, J1.4, J1.6, J1.21, J1.22, J1.23
/PSU12V: C4.1, F2.1, J1.10, J1.11
/PSUNEG: C2.2, J1.14, J2.4, R3.1, TP3.1 (1_1), U1.2 (VI)
/PSUSBY: J1.9
GND: C1.1, C2.1, C3.2, C4.2, D1.1 (K), D2.1 (K), D3.2 (A), D4.2 (A), D5.1 (K), J1.3, J1.5, J1.7, J1.15, J1.17, J1.18, J1.19, J1.24, J2.3, J2.6, SW1.1 (A), TP0.1 (1_1), U1.1 (GND)
unnamed: D1.2 (A), R1.2
unnamed: D2.2 (A), R2.2
unnamed: D3.1 (K), R3.2
unnamed: D4.1 (K), R4.2

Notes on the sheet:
GND PSON to turn on supply
12VDC Input is part of Pico PSU assembly
Micro fuses for 5V and 12V
Mechanical
-5V Regulator (from -12V)
Pico PSU DC-DC Converter
LED indicators for all rails
Apple //e supply connector

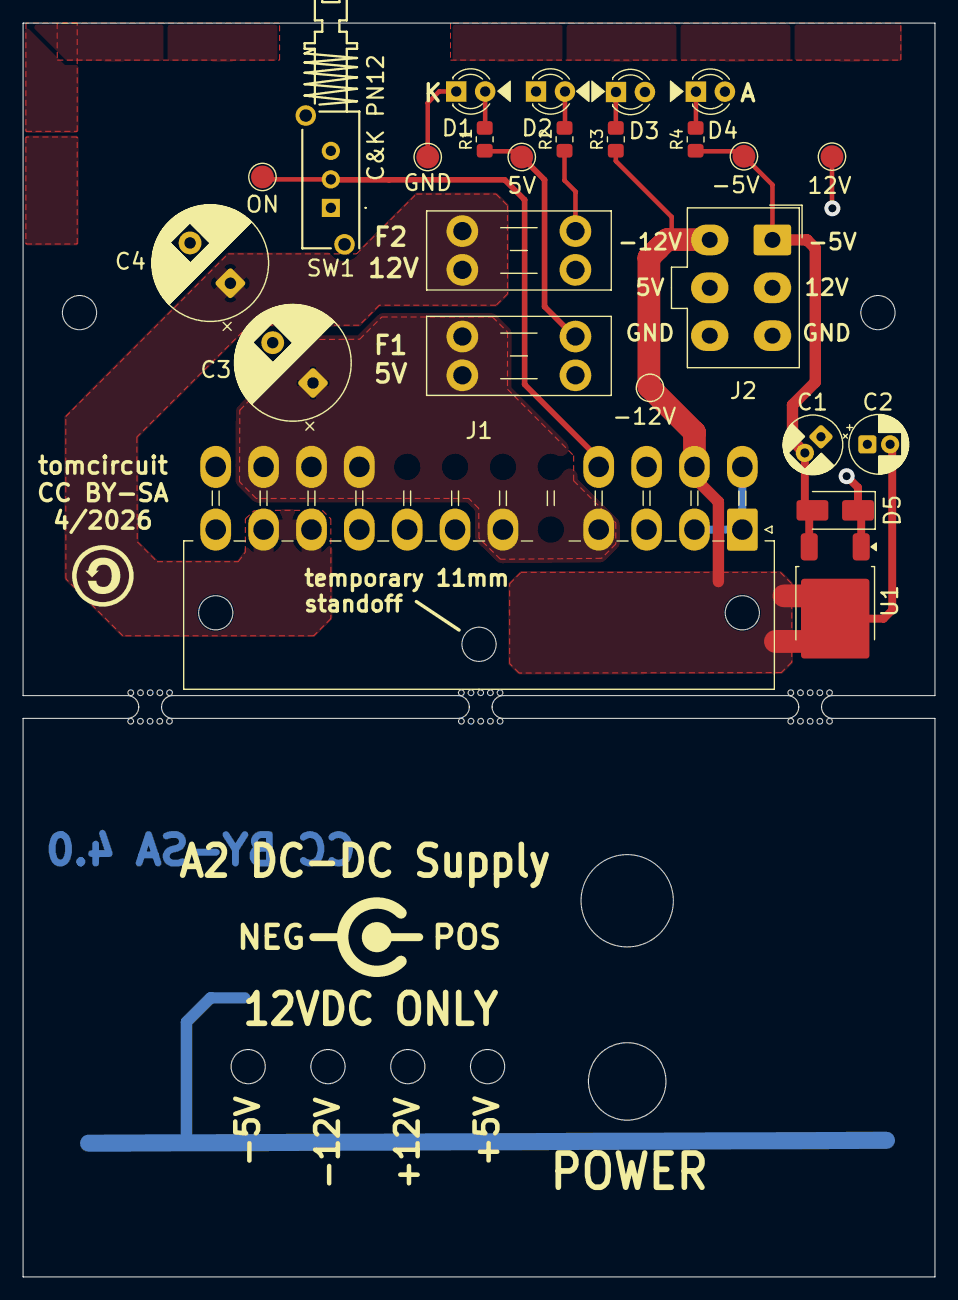
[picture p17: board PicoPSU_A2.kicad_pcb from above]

Board: 2 copper layers, 80.0 x 110.0 mm, 36 parts (1 on the bottom side), 13 nets.

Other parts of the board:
H1#2: 3mm; MountingHole_3mm

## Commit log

2026-05-02 Initial commit of 1v1
    Updated readme
    Added KiCad project files
    Added Fabrication files
    Added Plot files
    [PicoPSU_A2.kicad_pcb, PicoPSU_A2.kicad_sch]
2026-05-02 Delete Plots/Plots 1v0 directory
    removed 1v0 plot directory
    [PicoPSU_A2.csv]
2026-05-02 Update README.md
    added reference to 7905 heatsinking

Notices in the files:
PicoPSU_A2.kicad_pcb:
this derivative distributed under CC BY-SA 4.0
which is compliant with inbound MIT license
